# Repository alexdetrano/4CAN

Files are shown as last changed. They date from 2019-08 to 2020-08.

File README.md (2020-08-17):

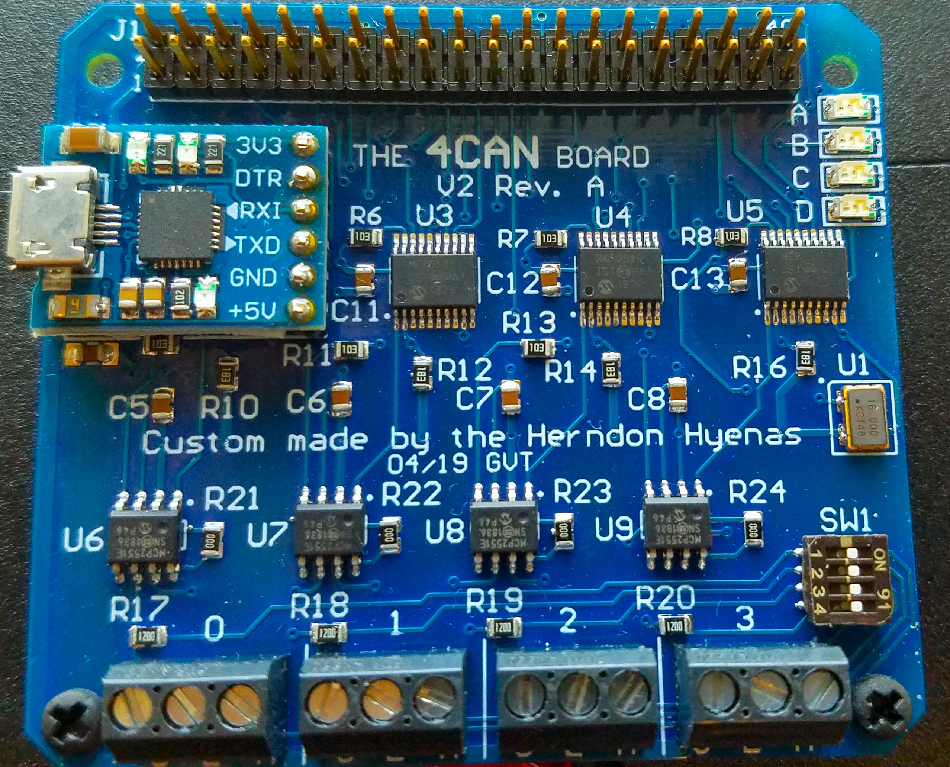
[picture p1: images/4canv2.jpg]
4canv2 picture


# what is this thing?
The 4CAN is a Raspberry Pi HAT which provides 4 CAN interfaces. The 4CAN is 100% compattible with socketcan and can-utils, and is very easy to get up and running.  A microUSB-UART serial adaptor is included to make troubleshooting the pi easier, and there are 4 LEDs on board, 2 of which are bidirectional green/red. And the best news of all is the 4CAN is open source, so you can build your own!

# why?
There aren't many _cheap_ devices which offer 4 CAN interfaces, compatible with socketcan, and is small, compact, and fits nicely with a Raspberry Pi.  Having 4 CAN busses allows testing 4 CAN buses simultaneously, as well as doing CAN-in-the-middle with 2 buses simultaneously. 

# hardware
Tested on the following raspbian images using a pi3b+
* [Apr 2019 (kernel 4.14.98-v7+)](http://downloads.raspberrypi.org/raspbian_lite/images/raspbian_lite-2019-04-09/)
* [Oct 2018 (kernel 4.14.71-v7+)](http://downloads.raspberrypi.org/raspbian_lite/images/raspbian_lite-2018-10-11/) 
* [Jun 2018 (kernel 4.14.50-v7+)](http://downloads.raspberrypi.org/raspbian_lite/images/raspbian_lite-2018-06-29/)

4can also works with the Raspberry pi 4
* [Sep 2019 (kernel 4.19.75-v7+](http://downloads.raspberrypi.org/raspbian_lite/images/raspbian_lite-2019-09-30/)

4can should also work with a pi0w, but it's recommended to use at least a pi3b. Also recommend using a heatsink on the pi, because the pi can get a little toasty running 4 can interfaces.

# install
run the install.sh script (requires sudo) to automatically install everything, and then reboot.

The install script will do the following:

1) Copy the 4 mcp2515-canx.dtbo files to /boot/overlays
```
sudo mkdir /boot/overlays/bak
sudo cp /boot/overlays/mcp2515* /boot/overlays/bak
sudo cp ./dtbo/*.dtbo /boot/overlays
```

2) append 4can setup to /boot/config.txt (makes a backup of original /boot/config.txt just in case)
```
sudo cp /boot/config.txt /boot/config.txt.bak
cat << EOF >> /boot/config.txt
# 4CAN setup
# the order of the interfaces matter
# ie can3,can2,can1,can0 must be preserved
# otherwise can0 will not REALLY be can0
dtparam=spi=on
dtoverlay=spi1-2cs

dtoverlay=mcp2515-can3,oscillator=16000000,interrupt=24
dtoverlay=mcp2515-can2,oscillator=16000000,interrupt=23
dtoverlay=mcp2515-can1,oscillator=16000000,interrupt=25
dtoverlay=mcp2515-can0,oscillator=16000000,interrupt=22

# enable uart
enable_uart=1
EOF
```

# usage
Before using 4can, make sure that the socketcan kernel module is loaded with `sudo modprobe can_dev`. This shouldn't be necessary since the pi will load the correct kernel module based on the device tree, but it doesn't hurt to check.

Once installed, run the 4can.sh to bring up CAN interfaces
`./4can.sh`

wire up the can interfaces and do `candump -acc any` to check they are working.
note: requires can-utils
to install `sudo apt install can-utils`

Note: Sometimes interfaces come up out of order, reboot the pi and that should fix it.
If not, you might have to modify /boot/config.txt. 

# GPIO
The 4can uses a number of GPIO on the raspberry pi. The GPIO pins available for use are
`3, 5, 8, 10, 27, 28, 32, 36` (physical pin numbering)

All the ground pins are tied together and can should be used as ground connections. The 3.3v, and 5v pins can be used to supply voltage as well.

Consult the [schematic](4can_sch.pdf) for more details.

## Recommended Wiring
Remember to connect the external CAN ground to the 4can ground (the "C" connection on the screw terminal). This will ensure good ground integrity and minimize tx/rx errors.

| | |
| --- | --- |
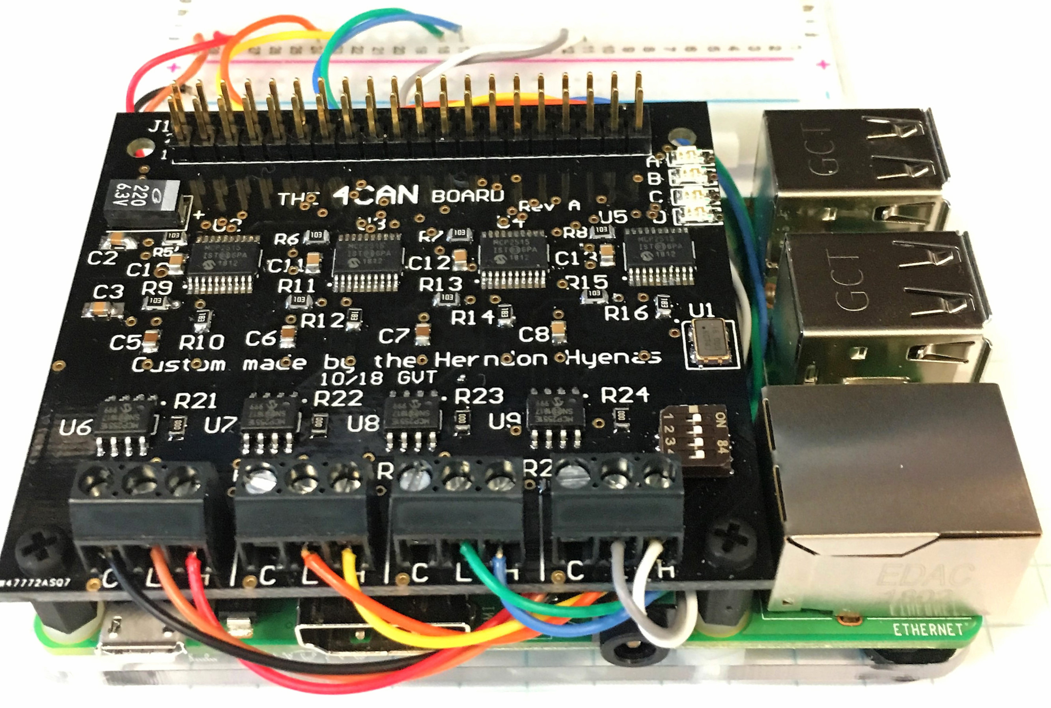
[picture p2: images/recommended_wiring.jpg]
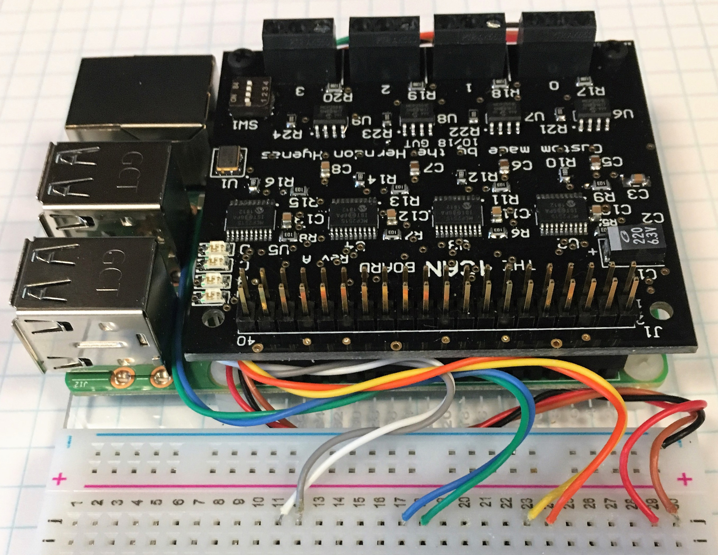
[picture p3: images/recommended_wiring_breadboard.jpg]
|  |   |

When using the 4can with the HyenaPlate, the CAN wires can be routed underneath the pi and connected to the breadboard. This is mainly for aesthetics, but other benefits include not having to constantly screw/unscrew the screw terminals to make new connections, easier troubleshooting, and more stable connections.  

For even more aesthetics, the [resistor color code](https://en.wikipedia.org/wiki/Electronic_color_code) can be used to assign colors to signals.  For example, in the image above:

| interface | CAN-L | CAN-H|
| --- | --- | --- |
| CAN0 | brown | red |
| CAN1 | orange | yellow |
| CAN2 | blue | violet |
| CAN3 | green | white |

black can be used for ground.

# Credit and License
## IndustrialBerry
The 4can was inspired by and is loosely based on the [IndustrialBerry QUAD CAN BUS adapter for Raspberry CanBerry](http://www.industrialberry.com/quad-can-bus-adapter-raspberry-canberry/CanBerry).  Although we modified the design to suit our needs, we must give credit to the fantastic work done by IndustrialBerry. The 4CAN, as well as the IndustrialBerry are licensed under a Creative Commons Attribution Share-Alike license.

## George Tarnovsky
Credit must also be given to George Tarnovsky, for schematic, layout, assembly, and verification!

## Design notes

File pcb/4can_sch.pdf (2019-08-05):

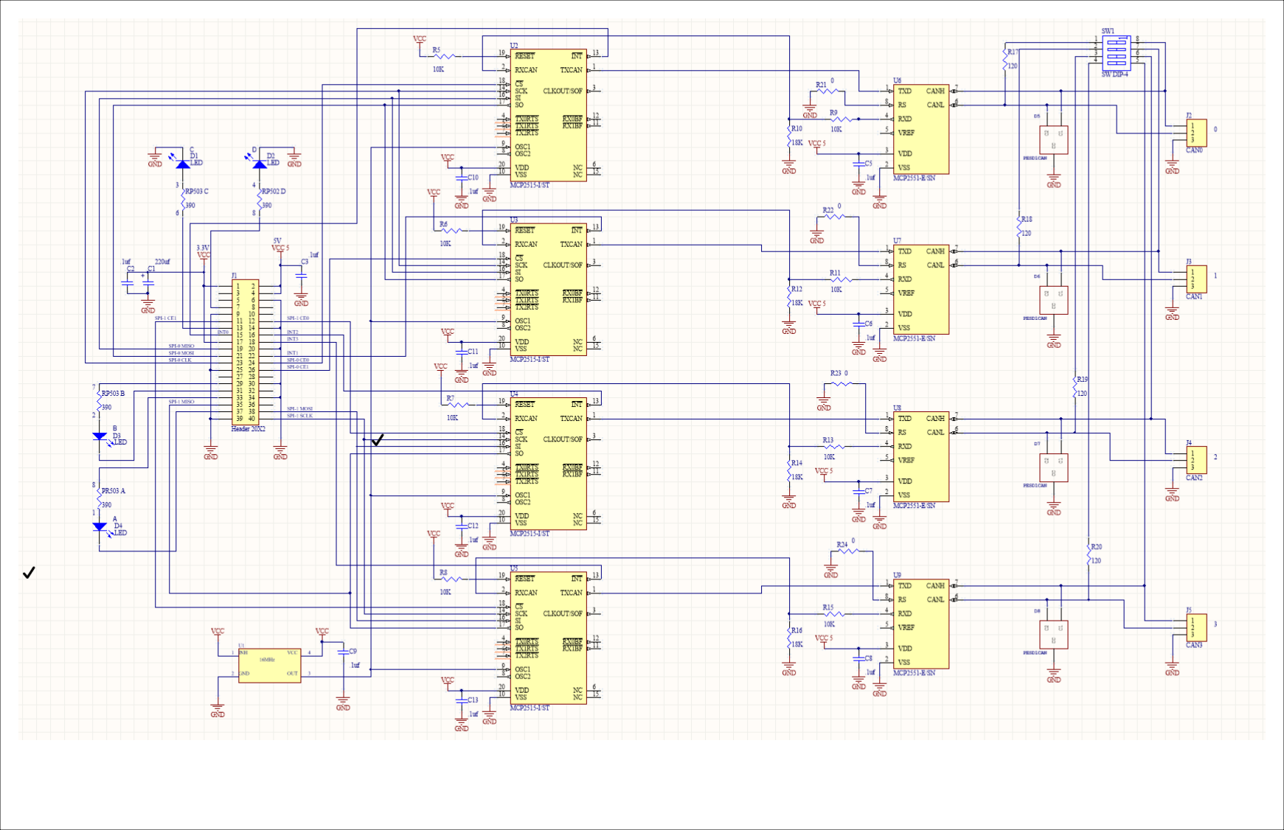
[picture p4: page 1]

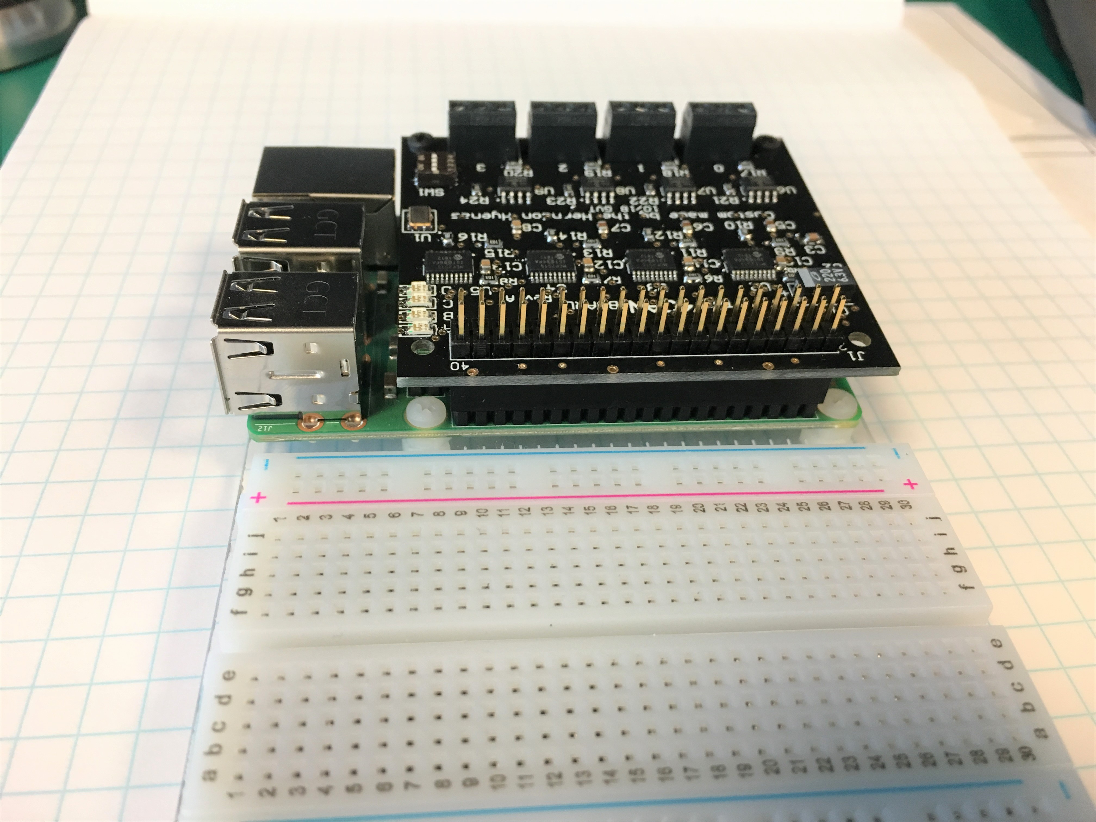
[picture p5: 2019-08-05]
images/4can_breadboard_side.jpg

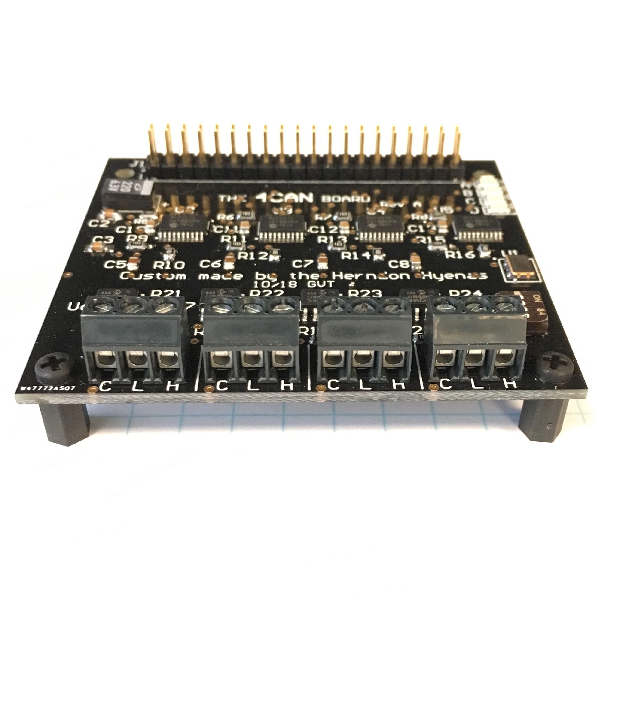
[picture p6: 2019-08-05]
images/4can_front.jpg

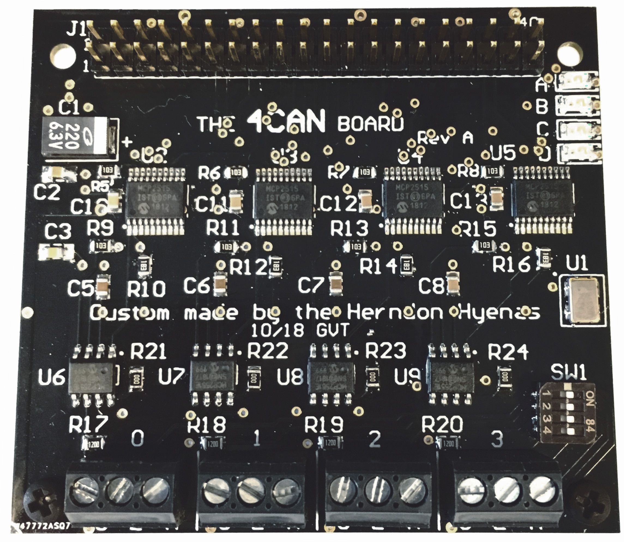
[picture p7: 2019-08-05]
images/4can_top.jpg

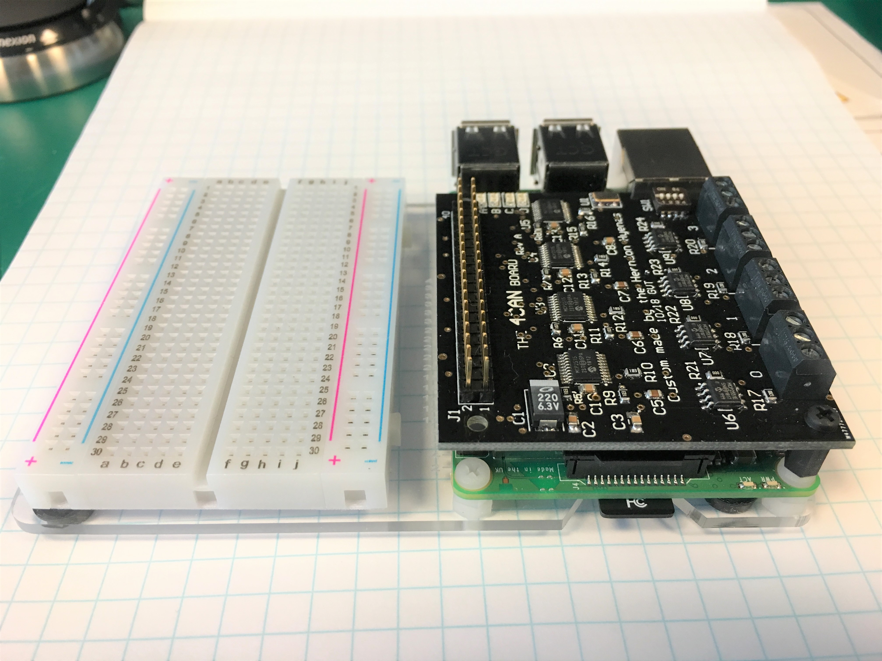
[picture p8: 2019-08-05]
images/4can_breadboard.jpg

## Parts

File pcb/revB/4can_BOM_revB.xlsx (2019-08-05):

Comment | Description | Designator | Footprint | Ref | Digikey P# | Quantity
220uf 6.3v tan |  | C1 | CC5750-2220 | F930J227MNC | 493-2345-1-ND | 1
.1uf |  | C2, C3 | C1206 | C0805Y103K1RACAUTO | 399-12963-1-ND | 2
.01uf |  | C5, C6, C7, C8, C9, C10, C11, C12, C13, | C0805 | CC0805ZRY5V9BB104 | 311-1361-6-ND | 9
Bi color LED |  | D1, D2, D3, D4 |  | XZMDKVG55W-4 | 1497-1314-1-ND | 4
CAN diode |  | D5, D6, D7, D8 | SOT23_N | PEGD1CAN.215 | 1727-3817-1-ND | 4
390 Ohm |  | RP1 | SO-G8/Z7.45 | 744C083391JP | 744C083391JPCT-ND | 1
16mHz osc. |  | U1 | SMD 4 | KC5032A16.0000 | 1253-1039-1-ND | 1
CAN Ctrl |  | U2, U3, U4, U5 | 20TSSOP | MCP2515T-I/ST | MCP2515-I/STCT-ND | 4
CAN Transceiver |  | U6, U7, U8, U9 | 8SOIC | MCP2551-E/SN | MCP2551-E/SN-ND | 4
4 pos dip switch |  | SW1 | 8SOIC | 218-4LPSTJ | CT3109-ND | 1
10k |  | R5, R6, R7, R8, R9, R11, R13, R15, | 805 | RC805JR-0710kL | 311-10k-KARCT-ND | 8
18k |  | R10, R12, R14, R16, | 805 | RC0805JR-0718KL | 311-18kARCT-ND | 4
120 Ohm |  | R17, R18, R19, R20, | 805 | RC0805FR-07120RL | 311-120CRCT-ND | 4
0 Ohm |  | R21, R22, R23, R24 | 805 | CRCW08050000Z0E | 541-4127-1-ND | 4
40 Pin header female |  | J1 | 40pin male DR 90d | NPTC202KFMS-RC | S5690-ND | 1
3 contact scew term |  | J2, J3, J4, J5 |  | ED555/XDS | ED1515-ND | 4
40 pin male header |  | J6 | 40 pin dual row | TSW-123-07-F-D | SAM12366-ND

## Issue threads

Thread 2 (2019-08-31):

Package Specifications and Footprints for KiCAD

Infiltra, 2019-08-31:
We are trying to create the board in KiCAD, and we can't find some packaged and footprints for KiCAD. Kindly assist on this issue.

For example, we don't have the RP with us and some more components as well. We tried creating the footprint ourselves but it was in vain effort.

Closed 2019-08-31.

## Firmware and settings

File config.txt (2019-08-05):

# For more options and information see
# http://rpf.io/configtxt
# Some settings may impact device functionality. See link above for details

# uncomment if you get no picture on HDMI for a default "safe" mode
#hdmi_safe=1

# uncomment this if your display has a black border of unused pixels visible
# and your display can output without overscan
#disable_overscan=1

# uncomment the following to adjust overscan. Use positive numbers if console
# goes off screen, and negative if there is too much border
#overscan_left=16
#overscan_right=16
#overscan_top=16
#overscan_bottom=16

# uncomment to force a console size. By default it will be display's size minus
# overscan.
#framebuffer_width=1280
#framebuffer_height=720

# uncomment if hdmi display is not detected and composite is being output
#hdmi_force_hotplug=1

# uncomment to force a specific HDMI mode (this will force VGA)
#hdmi_group=1
#hdmi_mode=1

# uncomment to force a HDMI mode rather than DVI. This can make audio work in
# DMT (computer monitor) modes
#hdmi_drive=2

# uncomment to increase signal to HDMI, if you have interference, blanking, or
# no display
#config_hdmi_boost=4

# uncomment for composite PAL
#sdtv_mode=2

#uncomment to overclock the arm. 700 MHz is the default.
#arm_freq=800

# Uncomment some or all of these to enable the optional hardware interfaces
#dtparam=i2c_arm=on
#dtparam=i2s=on
#dtparam=spi=on

# Uncomment this to enable the lirc-rpi module
#dtoverlay=lirc-rpi

# Additional overlays and parameters are documented /boot/overlays/README

# Enable audio (loads snd_bcm2835)
dtparam=audio=on

# 4CAN setup
# the order of the interfaces matter
# ie can3,can2,can1,can0 must be preserved
# otherwise can0 will not REALLY be can0
dtparam=spi=on
dtoverlay=spi1-2cs

dtoverlay=mcp2515-can3,oscillator=16000000,interrupt=24
dtoverlay=mcp2515-can2,oscillator=16000000,interrupt=23
dtoverlay=mcp2515-can1,oscillator=16000000,interrupt=25
dtoverlay=mcp2515-can0,oscillator=16000000,interrupt=22


# enable uart
enable_uart=1

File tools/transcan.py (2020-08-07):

#!/usr/bin/env python3
""" Map CAN IDs between 2 CAN buses"""
import time
import sys
import os
import can
import argparse
import asyncio
from dataclasses import dataclass

__author__ = "adetrano"

suffix = b'DBEEF'
can2hs = {'can0': 0, 
          'can1': 1,
          'can2': 2,
          'can3': 3
}

def autoint(x):
    """Stupid helper function so we can pass in hex values and not have to convert from string"""
    return int(x,0)

# eq=True allows us to make comparisons of instances
# frozen=True creates a __hash__ so we can add it to hashed collections
@dataclass(eq=True, frozen=True)
class MsgMap:
    """Dataclass to store received messages"""
    tx_ch : int
    rx_ch : int
    tx_id : int
    rx_id : int
    difference: int

    def __repr__(self):
        return f'tx_bus={self.tx_ch} rx_bus={self.rx_ch} tx_id=0x{self.tx_id:03x} rx_id=0x{self.rx_id:03x} difference={self.difference}'

class Listener(can.Listener):
    def __init__(self):
        self.hits = []
        self.msg_map = set()

    def on_message_received(self, msg):
        """Callback for whenever a message is received on CAN bus"""
        if suffix in msg.data:
            self.hits.append(msg)

    def process_messages(self):
        """Extract the source ID from received messages"""
        for msg in self.hits:
            tx_ch = (msg.data[0] >> 4) & 0x0f
            rx_ch = msg.data[0] & 0x0f
            
            tx_id = bytearray(3)
            # we only want upper 3 nibbles
            tx_id[0] = msg.data[1] & 0x0F         # strip off leading zero
            tx_id[1] = (msg.data[2] & 0xF0) >> 4  # upper byte
            tx_id[2] = (msg.data[2] & 0x0F)       # lower byte
            tx_id = (tx_id[0] << 8) | (tx_id[1] << 4) | tx_id[0]
            rx_id = msg.arbitration_id
            difference = int(tx_id != rx_id)
            self.msg_map.add(MsgMap(tx_ch, rx_ch, tx_id, rx_id, difference))


    def print_messages(self):
        """Print out received messages"""
        for msg in self.msg_map:
            print(msg)

class Bus2Bus:
    def __init__(self, src_bus, dst_bus, start_id=0x0, end_id=0x7ff, msg_repeat=5, delay=0.1):
        self.src_bus = can.interface.Bus(src_bus, bustype='socketcan')
        self.dst_bus = can.interface.Bus(dst_bus, bustype='socketcan')
        self.listener = Listener()
        self.notifier = can.Notifier(self.dst_bus, [self.listener])
        self.start_id = start_id
        self.end_id = end_id
        self.src_ch = self.src_bus.channel
        self.dst_ch = self.dst_bus.channel
        self.msg_repeat = msg_repeat
        self.delay = delay

    def send_msgs(self):
        """Send encoded messages

           messages encoded as follows:
             msg[0] = {tx_bus, rx_bus} - packed into an char
             msg[1:2] = original arbitration ID
             msg[3:7] = b'DBEEF' - look for these bytes on the RX channel
        """
        bus_prefix = (can2hs[self.src_ch] << 4) | can2hs[self.dst_ch]
        bus_prefix = bus_prefix.to_bytes(1, byteorder='big')
        print(f'Sending messages from {self.src_ch} to {self.dst_ch}', file=sys.stderr)
        for id in range(self.start_id, self.end_id+1):
            # include the sending ID as part of the payload
            # so we know original sent ID
            can_id = (id).to_bytes(2, byteorder='big')
            payload = bus_prefix + can_id + suffix

            # extended_id determines if ID is 29 bits or 7 bits
            msg = can.Message(arbitration_id=id, data=payload, extended_id=False)

            # send message multiple times to ensure our script detects it
            # sometimes sending once causes the script to miss it
            print(f'Sending 0x{id:03x}', end='\r', file=sys.stderr)
            for _ in range(self.msg_repeat):
                self.src_bus.send(msg)
                time.sleep(self.delay)

    def process_msgs(self):
        """Check to see if any messages contain our string"""
        self.listener.process_messages()

    def print_msgs(self):
        """Pretty print any matching messages"""
        self.listener.print_messages()

    def cleanup(self):
        """Gracefully cleanup once we are done"""
        self.listener.stop()
        self.src_bus.shutdown()
        self.dst_bus.shutdown()

def usage():
    script_name = os.path.basename(sys.argv[0])
    print('Usage: {} send_if recv_if'.format(script_name))
    print('eg {} can0 can1'.format(script_name))
    print('requires python-can - install with `pip3 install python-can`')

def parse_args(args):
    parser = argparse.ArgumentParser(description='Test interbus CAN bus connectivity')
    parser.add_argument('src', metavar='src_interface', help='interface to send CAN messages from')
    parser.add_argument('dst', metavar='dst_interface', help='interface to receive CAN messages on')
    parser.add_argument('--start_id', default=0x0,  type=autoint, help='CAN ID to start testing with eg 0x600')
    parser.add_argument('--end_id', default=0x7ff, type=autoint, help='CAN ID to start testing with eg 0x7ff')
    parser.add_argument('--msg_repeat', default=5, type=int, help='Number of times to repeat sending a message')
    parser.add_argument('--delay', default=0.1, type=float, help='Time to wait between sending messages')
    #parser.add_argument('--permute', nargs='+', metavar='interface', help='send/receive on all possible interface permutations')

    return parser.parse_args(args)

def main():
    args = parse_args(sys.argv[1:])
    bus2bus = Bus2Bus(args.src, args.dst, args.start_id, args.end_id, args.msg_repeat, args.delay)
    bus2bus.send_msgs()
    bus2bus.process_msgs()
    bus2bus.print_msgs()
    bus2bus.cleanup()

if __name__ == '__main__':
    main()

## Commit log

2020-08-06 added better arg parsing and broke out parsing into its own class
    [transcan.py]
2020-08-17 force can interfaces to have proper assignment based on their SPI address eg 0.0 is can0, 0.1 is can1, 1.0 is can2, 1.1 is can3
